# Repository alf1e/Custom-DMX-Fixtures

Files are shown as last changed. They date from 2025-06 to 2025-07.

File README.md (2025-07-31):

# Alfie's Custom DMX Fixtures
## What is this?
This project contains any relevant files for Custom DMX Fixtures project. In this repository you can find a PCB controller board, compatible with Neopixel LEDs using WLED. A fixture board which converts the signal sent from the controller to something usable by the Neopixel strip. And a LED Bar Fixture using the 24V version of the fixture control board.

## Why did you make this?
I volunteer at my school running our lighting rig for our shows. After one show in February, I realised something was missing and that it would look awesome with some kind of bar fixture. So I started this project and here we are now :D

# Images
Here are some relevant pictures of my project. Ill add more as I have then and as is needed.

## Control Board
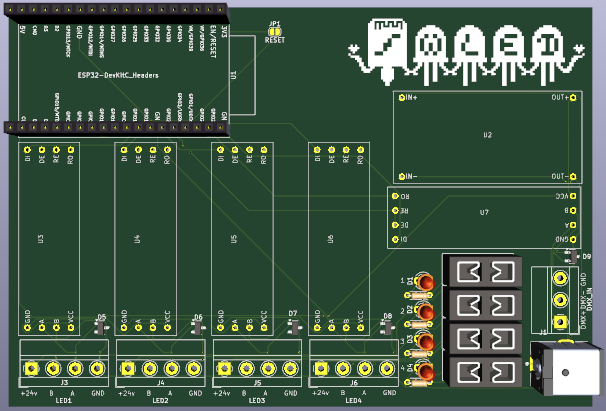
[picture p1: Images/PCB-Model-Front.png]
Picture of PCB Model Front

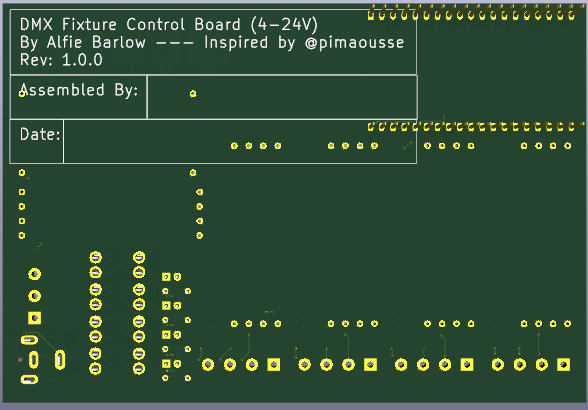
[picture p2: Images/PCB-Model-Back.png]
Picture of PCB Model Back


## 24V Fixture Board
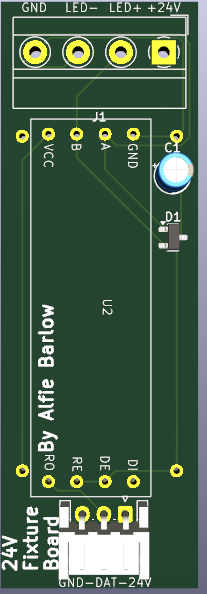
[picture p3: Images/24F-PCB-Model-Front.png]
Picture of PCB Model Front

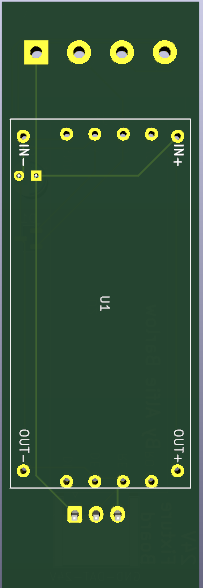
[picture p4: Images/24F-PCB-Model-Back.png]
Picture of PCB Model Back


# Firmware
For the firmware, you can use any compilation of WLED with DMX enabled.

You can compile WLED at [this website](https://wled-compile.github.io/?lang=en) using my config file in the root of this repository called `firmware.json`

# External Wiring
A DMX Fixture is basically a fancy name for a software controlled light, usually in a theatrical setting. My Fixtures are connected to the controlled using a GX12-4 cable matching 24V with 24V, A with LED-, B with LED+ and GND with GND. Relatively simple!

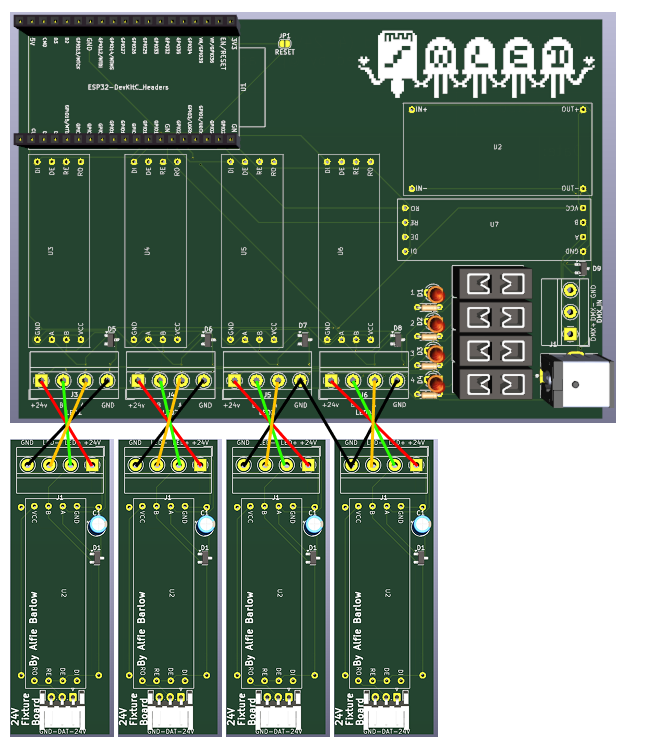
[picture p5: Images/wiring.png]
Picture of Wiring


# How to use.
Once you have the firmware installed there is 2 ways you can use this.

## No DMX
This can be purely controlled by any WLED control software. For mobile, I use WLED Native or just go to the IP of the controller on desktop. You can then change the colour and set effects through here

## DMX
This is a bit more complicated. Once you have connected the controller to your computer via a DMX interface you can open any DMX control software like QLC+ and import the configuration of the lights (Coming soon! I cant create a configuration without having at least a prototype) and then you can control the lights through QLC+. Remember to make sure you have no overlapping channels though!

# BOM
The following table and `BOM.csv` file are a combination of 4x 24V LED Bar Fixtures and 1x Control Board. For the individual BOMs see `BOM.md`

**Total BOM Cost: $223.09**

|Mrf# |Mfr. |Order Qty.|Unit Price(USD)|Ext.Price(USD)|LCSC# |Package |Min|Mult|SPQ |Availability|Stock Status|Customer Notes|Description |Product Link |
|---|---|---|---|---|---|---|---|----|----|---|---|---|---|---|
|TZ-L2-03YYBG2TDJ30-002|TUOZHAN |20 |0.0213 |0.43 |C779432  |Through Hole,D=3mm |20 |20  |1000|300 |In Stock | |Emerald Green 3mm Round Lens Through Hole,D=3mm LED Indication - Discrete ROHS |https://lcsc.com/product-detail/led-indication-discrete_tuozhan-tz-l2-03yybg2tdj30-002_C779432.html |
|NUP2105L |(DIOTEC) |10 |0.0899 |0.9 |C3700834 |SOT-23-3 |5  |5 |3000|45 |In Stock | |8A@8/20us 350W 44V 26.2V 24V SOT-23-3 ESD and Surge Protection (TVS/ESD) ROHS |https://lcsc.com/product-detail/esd-and-surge-protection-tvs-esd_diotec-nup2105l_C3700834.html |
|178.6165.0002 |Littelfuse |4 |2.1355 |8.54 |C207061  |Through Hole |1  |1 |500 |2007 |In Stock | |Through Hole Fuseholders ROHS |https://lcsc.com/product-detail/fuseholders_littelfuse-178-6165-0002_C207061.html |
|DB302-5.0-3P-GN-S |DORABO |5 |0.2851 |1.43 |C2997276 |P=5mm |5  |5 |500 |1085 |In Stock | |1x3P -40℃~+105℃ 30A 300V Green Through Hole 5mm 1 3 P=5mm Screw Terminal Blocks ROHS |https://lcsc.com/product-detail/screw-terminal-blocks_dorabo-db302-5-0-3p-gn-s_C2997276.html |
|2.54-1*4P |BOOMELE(Boom Precision Elec)|20 |0.0469 |0.94 |C2718488 |Through Hole,P=2.54mm |10 |10  |1000|38270 |In Stock | |2.54mm 1 3A 4P Bronze -40℃~+105℃ Through Hole 1x4P Top Square Hole Through Hole,P=2.54mm Female Headers ROHS |https://lcsc.com/product-detail/female-headers_boomele-boom-precision-elec-2-54-1-4p_C2718488.html |
|PM254-1-19-Z-8.5 |HCTL |5 |0.3055 |1.53 |C2897382 |Through Hole,P=2.54mm |5  |5 |120 |6380 |In Stock | |2.54mm 1 3A Copper Alloy 19P -40℃~+105℃ Through Hole 1x19P 8.5mm Top Square Hole Through Hole,P=2.54mm Female Headers ROHS  |https://lcsc.com/product-detail/female-headers_hctl-pm254-1-19-z-8-5_C2897382.html |
|ZX-PZ2.54-1-1PZZ |Megastar |20 |0.0116 |0.23 |C7501259 |Through Hole,P=2.54mm |20 |20  |2000|33300 |In Stock | |Gold 3A Through Hole Pin Header 2.5mm 1P 6mm -40℃~+105℃ 3mm 2.54mm Brass Black 1 1x1P Through Hole,P=2.54mm Pin Headers ROHS|https://lcsc.com/product-detail/pin-headers_megastar-zx-pz2-54-1-1pzz_C7501259.html |
|DB302-5.0-4P-GN-S |DORABO |8 |0.4435 |3.55 |C5143708 |Through Hole,P=5mm |1  |1 |200 |647 |In Stock | |20A 1x4P -40℃~+105℃ 300V Green Through Hole 5mm 1 4 Through Hole,P=5mm Screw Terminal Blocks ROHS |https://lcsc.com/product-detail/screw-terminal-blocks_dorabo-db302-5-0-4p-gn-s_C5143708.html |
|MFR-25FTE52-4K7 |YAGEO |50 |0.0117 |0.59 |C173023  |Through Hole,D2.4xL6.3mm |50 |50  |5000|62150 |In Stock | |Metal Film Resistor 4.7kΩ 250mW ±50ppm/℃ ±1% Through Hole,D2.4xL6.3mm Through Hole Resistors ROHS |https://lcsc.com/product-detail/through-hole-resistors_yageo-mfr-25fte52-4k7_C173023.html |
|0287002.PXCN |Littelfuse |5 |0.1083 |0.54 |C142680  |- |5  |5 |2000|2320 |In Stock | |32V 1kA Blade Fuse 2A Automotive Fuses ROHS |https://lcsc.com/product-detail/automotive-fuses_littelfuse-0287002-pxcn_C142680.html |
|DC-508-ARL250-H069 |XUNPU |1 |1.3904 |1.39 |C34388679|Through Hole |1  |1 |400 |357 |In Stock | |Right Angle DC Power Jack -40℃~+85℃ 2.5mm 5.7mm 20A 30V Through Hole DC Power Connectors ROHS |https://lcsc.com/product-detail/dc-power-connectors_xunpu-dc-508-arl250-h069_C34388679.html |
|S3B-EH(LF)(SN) |JST |10 |0.0458 |0.46 |C263754  |Through Hole,Right Angle,P=2.5mm|10 |10  |1000|60 |In Stock | |1x3P 3P EH Tin 3 -25℃~+85℃ 3A 1 2.5mm Brass Right Angle Through Hole,Right Angle,P=2.5mm Wire To Board Connector ROHS |https://lcsc.com/product-detail/wire-to-board-connector_jst-s3b-eh-lf-sn_C263754.html |
|- |- |5 |0.98 |4.9 |- |- |-  |- |- |- |- | |LM2596 |https://www.aliexpress.com/item/1005004904872120.html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 |
|- |- |9 |0.28 |2.52 |- |- |-  |- |- |- |- | |RS-485 TTL |https://www.aliexpress.com/item/1005005737922222.html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 |
|- |- |1 |3.42 |3.42 |- |- |-  |- |- |- |- | |ESP32-DevKitC |https://www.aliexpress.com/item/1005007820190456.html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 |
|- |- |1 |13.4 |13.4 |- |- |-  |- |- |- |- | |Control Board PCB | |
|- |- |4 |6 |24 |- |- |-  |- |- |- |- | |24V Fixture PCB | |
|- |- |4 |20.21 |80.84 |- |- |-  |- |- |- |- | |Polycarbonate Tube |https://www.ebay.co.uk/itm/276693351932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|
|- |- |4 |14.57 |58.28 |- |- |-  |- |- |- |- | |WS2811-COB |https://www.aliexpress.com/item/1005008502347105.html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 |
|- |- |1 |10.99 |10.99 |- |- |-  |- |- |- |- | |24V 10A PSU |https://www.aliexpress.com/item/1005005763465796.html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 |
|- |- |1 |3.04 |3.04 |- |- |-  |- |- |- |- | |DMX Input |https://www.aliexpress.com/item/1005007432049215.html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 |
|- |- |8 |0.32 |2.56 |- |- |-  |- |- |- |- | |Fixture Connectors |https://www.aliexpress.com/item/1005002920441877.html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 |

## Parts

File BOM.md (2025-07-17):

# DMX Control Board
* [BOM](https://github.com/alf1e/Custom-DMX-Fixtures/blob/main/DMX%20Control%20Board/BOM.csv)
* [Digikey BOM](https://github.com/alf1e/Custom-DMX-Fixtures/blob/main/DMX%20Control%20Board/BOM-digikey.csv)
* [Other BOM](https://github.com/alf1e/Custom-DMX-Fixtures/blob/main/DMX%20Control%20Board/BOM-other.csv)

# 24V Fixture Board
* [BOM](https://github.com/alf1e/Custom-DMX-Fixtures/blob/main/24V%Fixture%20Board/BOM.csv)
* [Digikey BOM](https://github.com/alf1e/Custom-DMX-Fixtures/blob/main/24V%Fixture%20Board/BOM-digikey.csv)
* [Other BOM](https://github.com/alf1e/Custom-DMX-Fixtures/blob/main/24V%Fixture%20Board/BOM-other.csv)

# 24V LED Bar Fixture
* [BOM](https://github.com/alf1e/Custom-DMX-Fixtures/blob/main/24V%LED%Bar%20Fixture/BOM.csv)

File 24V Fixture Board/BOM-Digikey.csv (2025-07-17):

Index | Manufacturer Part Number | Manufacturer Name | Description | Requested Quantity 1 | Pack Quantity 1 | Pack Type 1 | Digi-Key Part Number 1 | Unit Price 1 | Extended Price 1 | Product Notes
1 | PPTC041LFBN-RC | Sullins Connector Solutions | CONN HDR 4POS 0.1 TIN PCB | 2 | 2 | Box | S7002-ND | 0.37 | $0.74
2 | 87224-1 | TE Connectivity AMP Connectors | CONN HEADER VERT 1POS | 4 | 4 | Bulk | A26541-ND | 0.65 | $2.60
3 | NUP2105L | Diotec Semiconductor | TVS DIODE 24VWM 44VC SOT233 | 1 | 1 | Cut Tape (CT) | 4878-NUP2105LCT-ND | 0.23 | $0.23
4 | 31059104 | METZ CONNECT USA Inc. | SCREW TYPE, TERMINAL BLOCK, RIGH | 1 | 1 | Bulk | 1849-1341-ND | 2.12 | $2.12
5 | S3B-EH | JST Sales America Inc. | CONN HEADER R/A 3POS 2.5MM | 1 | 1 | Bulk | 455-S3B-EH-ND | 0.11 | $0.11

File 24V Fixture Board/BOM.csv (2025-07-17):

Index | Manufacturer Part Number | Manufacturer Name | Description | Requested Quantity 1 | Pack Quantity 1 | Pack Type 1 | Digi-Key Part Number 1 | Unit Price 1 | Extended Price 1 | Product Notes
1 | PPTC041LFBN-RC | Sullins Connector Solutions | CONN HDR 4POS 0.1 TIN PCB | 2 | 2 | Box | S7002-ND | 0.37 | $0.74
2 | 87224-1 | TE Connectivity AMP Connectors | CONN HEADER VERT 1POS | 4 | 4 | Bulk | A26541-ND | 0.65 | $2.60
3 | NUP2105L | Diotec Semiconductor | TVS DIODE 24VWM 44VC SOT233 | 1 | 1 | Cut Tape (CT) | 4878-NUP2105LCT-ND | 0.23 | $0.23
4 | 31059104 | METZ CONNECT USA Inc. | SCREW TYPE, TERMINAL BLOCK, RIGH | 1 | 1 | Bulk | 1849-1341-ND | 2.12 | $2.12
5 | S3B-EH | JST Sales America Inc. | CONN HEADER R/A 3POS 2.5MM | 1 | 1 | Bulk | 455-S3B-EH-ND | 0.11 | $0.11
6 | LM2596 | N/A |  | 1 | N/A | N/A | N/A | 0.98 | $0.98 | https://www.aliexpress.com/item/1005004904872120.html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
7 | RS-485 TTL | N/A |  | 1 | N/A | N/A | N/A | 0.28 | $0.28 | https://www.aliexpress.com/item/1005005737922222.html?mp=1
8 | PCB | N/A |  | 1 | N/A | N/A | N/A | 6 | $6

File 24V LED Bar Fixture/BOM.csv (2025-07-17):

Index | Manufacturer Part Number | Manufacturer Name | Description | Requested Quantity 1 | Pack Quantity 1 | Pack Type 1 | Digi-Key Part Number 1 | Unit Price 1 | Extended Price 1 | Product Notes
1 | N/A | N/A | 24V Fixture Board | 1 | N/A | N/A | N/A | 12.26 | $12.26
2 | N/A | N/A | N/A | 1 | N/A | N/A | N/A | 20.21 | $20.21 | https://www.ebay.co.uk/itm/276693351932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
3 | WS2811-FCOB | N/A | N/A | 1 | N/A | N/A | N/A | 14.57 | $14.57 | https://www.aliexpress.com/item/1005008502347105.html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

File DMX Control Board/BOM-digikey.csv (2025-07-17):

Index | Manufacturer Part Number | Manufacturer Name | Description | Requested Quantity 1 | Pack Quantity 1 | Digi-Key Part Number 1 | Unit Price 1 | Extended Price 1 | Product Notes
1 | 151031VS06000 | Würth Elektronik | LED GREEN DIFFUSED 3MM ROUND T/H | 4 | 4 | 732-5008-ND | 0.15 | $0.60
2 | NUP2105L | Diotec Semiconductor | TVS DIODE 24VWM 44VC SOT233 | 5 | 5 | 4878-NUP2105LCT-ND | 0.23 | $1.15
3 | 3568 | Keystone Electronics | FUSE HOLDER BLADE 500V 30A PCB | 4 | 4 | 36-3568-ND | 1.2 | $4.80
4 | 31271103 | METZ CONNECT USA Inc. | SCREW TYPE, TERMINAL BLOCK, RIGH | 1 | 1 | 1849-1335-ND | 1.56 | $1.56
5 | PPTC041LFBN-RC | Sullins Connector Solutions | CONN HDR 4POS 0.1 TIN PCB | 10 | 10 | S7002-ND | 0.313 | $3.13
6 | PPTC191LFBN-RC | Sullins Connector Solutions | CONN HDR 19POS 0.1 TIN PCB | 2 | 2 | S7017-ND | 1.05 | $2.10
7 | 87224-1 | TE Connectivity AMP Connectors | CONN HEADER VERT 1POS | 4 | 4 | A26541-ND | 0.65 | $2.60
8 | 31059104 | METZ CONNECT USA Inc. | SCREW TYPE, TERMINAL BLOCK, RIGH | 4 | 4 | 1849-1341-ND | 2.12 | $8.48
9 | CF12JT4K70 | Stackpole Electronics Inc | RES 4.7K OHM 5% 1/2W AXIAL | 4 | 4 | CF12JT4K70CT-ND | 0.1 | $0.40
10 | 0287002.PXCN | Littelfuse Inc. | FUSE AUTO 2A 32VDC BLADE ATO/ATC | 3 | 3 | F4192-ND | 0.39 | $1.17
11 | PJ-063AH | Same Sky (Formerly CUI Devices) | CONN PWR JACK 2X5.5MM SOLDER | 1 | 1 | CP-063AH-ND | 1.5 | $1.50
12 | 0287001.U | Littelfuse Inc. | FUSE AUTO 1A 32VDC BLADE ATO/ATC | 1 | 1 | 0287001.U-ND | 0.43 | $0.43

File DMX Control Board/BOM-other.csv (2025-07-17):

Index | Manufacturer Part Number | Manufacturer Name | Description | Requested Quantity 1 | Pack Quantity 1 | Digi-Key Part Number 1 | Unit Price 1 | Extended Price 1 | Product Notes
1 | LM2596 | N/A | N/A | 1 | N/A | N/A | 0.98 | $0.98 | https://www.aliexpress.com/item/1005004904872120.html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
2 | RS-485 TTL | N/A | N/A | 5 | N/A | N/A | 0.28 | $0.28 | https://www.aliexpress.com/item/1005005737922222.html?mp=1
3 | ESP32-DevKitC | N/A | N/A | 1 | N/A | N/A | 3.42 | $3.42 | https://www.aliexpress.com/item/1005007820190456.html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
4 | PCB | N/A | N/A | 1 | N/A | N/A | 13.4 | $13.4

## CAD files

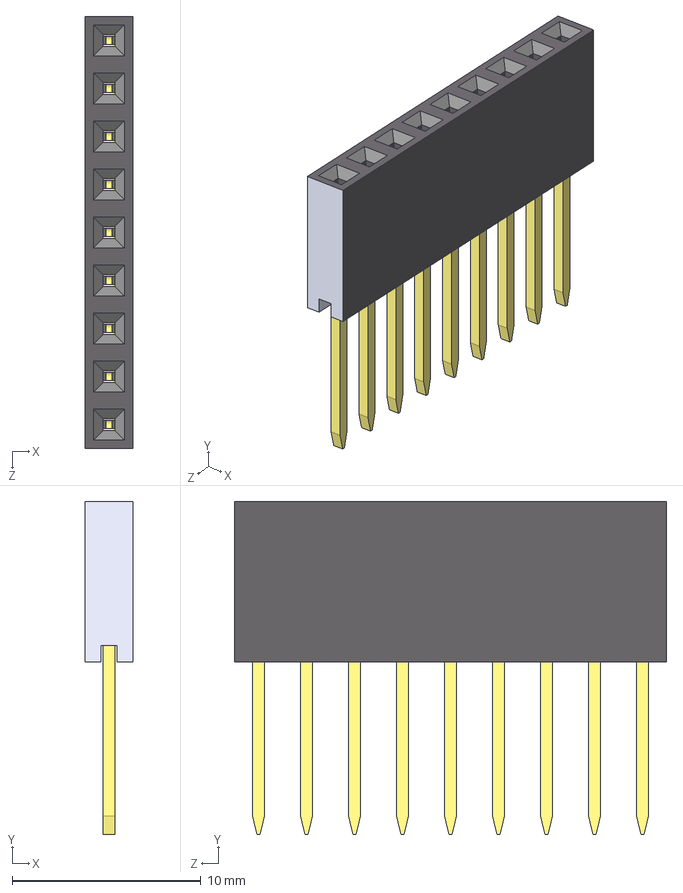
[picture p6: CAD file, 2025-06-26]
Models/header-female-15x1-1.snapshot.4/1x9.STEP
2.54 x 17.6 x 22.9 mm

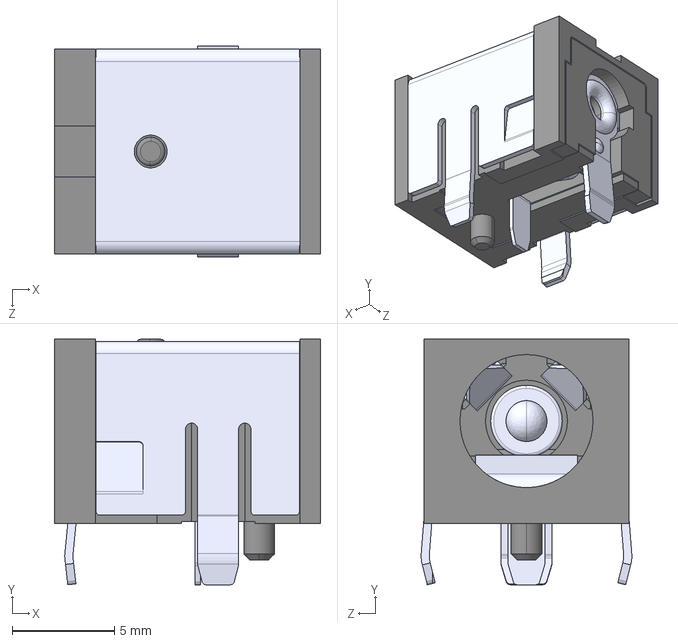
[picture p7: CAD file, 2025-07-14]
Models/PJ_063AH/PJ-063AH.step
13.0 x 12.0 x 10.3 mm

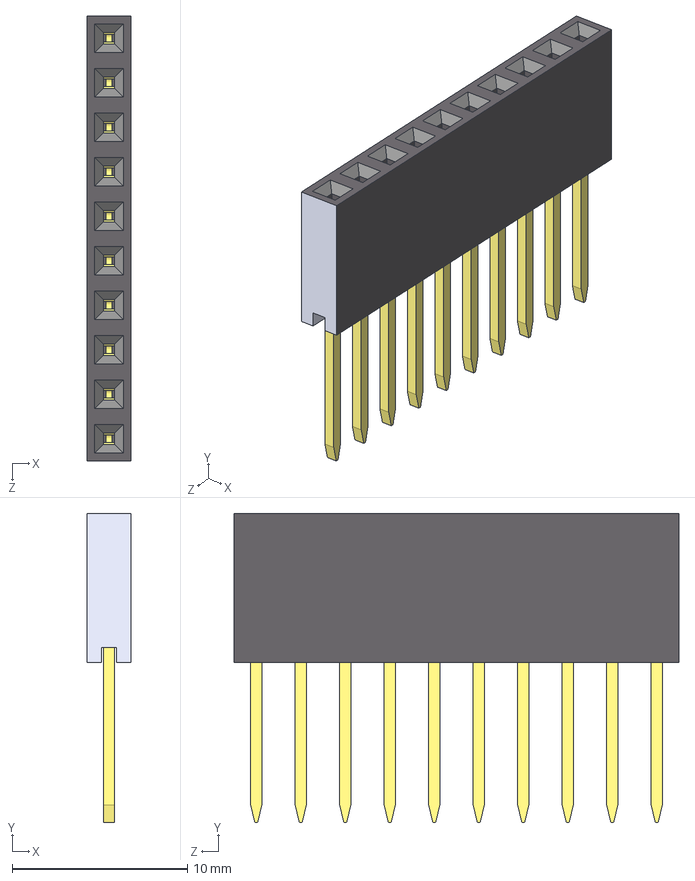
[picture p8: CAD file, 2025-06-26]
Models/header-female-15x1-1.snapshot.4/1x10.STEP
2.54 x 17.6 x 25.4 mm

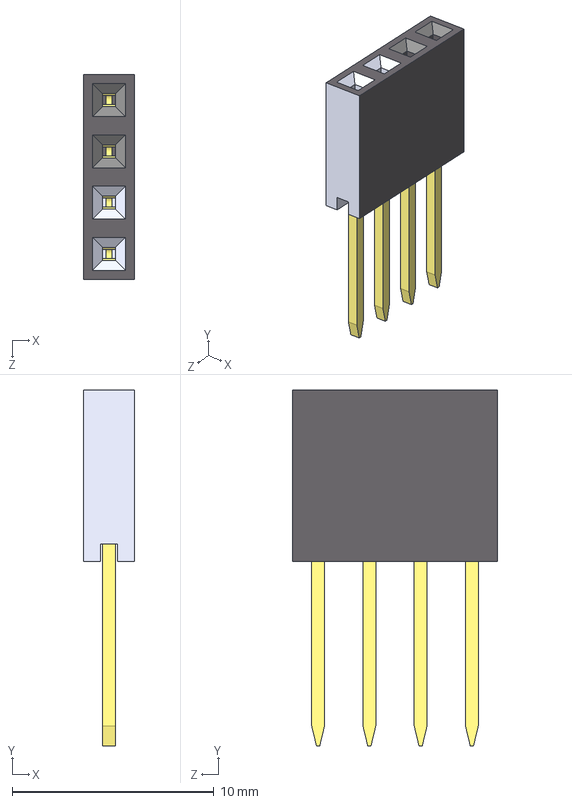
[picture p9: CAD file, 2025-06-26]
Models/header-female-15x1-1.snapshot.4/1x4.STEP
2.54 x 17.6 x 10.2 mm

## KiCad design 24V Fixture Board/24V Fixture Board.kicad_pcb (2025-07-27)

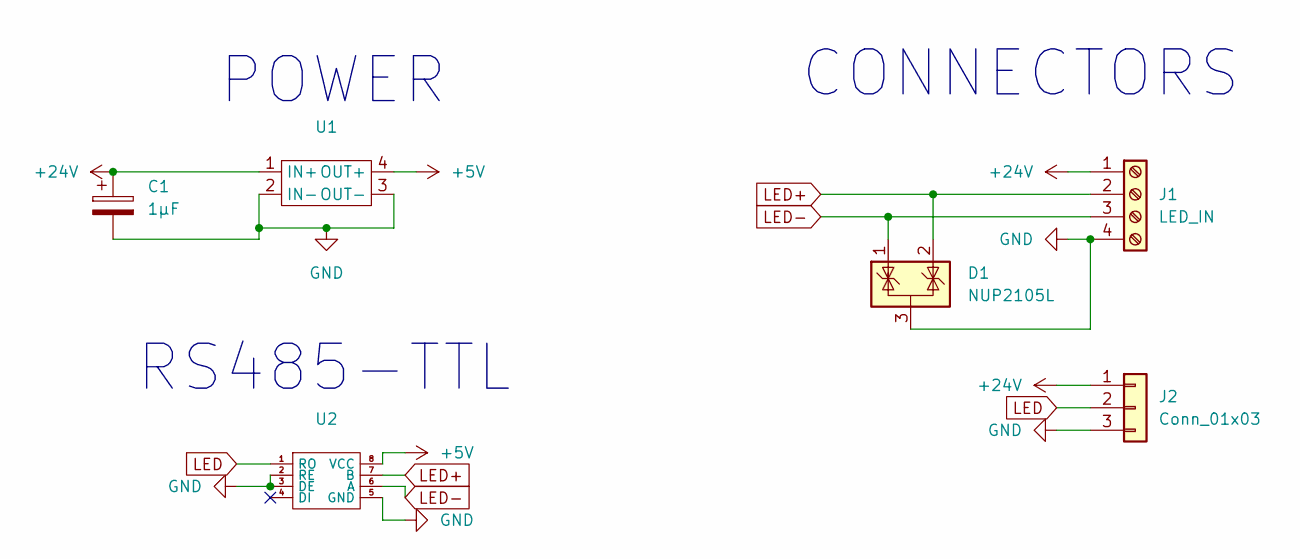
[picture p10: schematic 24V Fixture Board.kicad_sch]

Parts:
C1: 1μF; CP_Radial_D4.0mm_P2.00mm
D1: NUP2105L; SOT-23
J1: LED_IN; TerminalBlock_MetzConnect_Type011_RT05504HBWC_1x04_P5.00mm_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
J2: Conn_01x03; JST_EH_S3B-EH_1x03_P2.50mm_Horizontal
U1: LM2596S-Buck-Module
U2: Max485

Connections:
+5V: U1.4 (OUT+), U2.8 (VCC)
+24V: C1.1, J1.1, J2.1, U1.1 (IN+)
GND: C1.2, D1.3 (A), J1.4, J2.3, U1.2 (IN-), U1.3 (OUT-), U2.2 (RE), U2.3 (DE), U2.5 (GND)
LED: J2.2, U2.1 (RO)
LED+: D1.2 (K), J1.2, U2.7 (B)
LED-: D1.1 (K), J1.3, U2.6 (A)

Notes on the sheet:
CONNECTORS
POWER
RS485-TTL

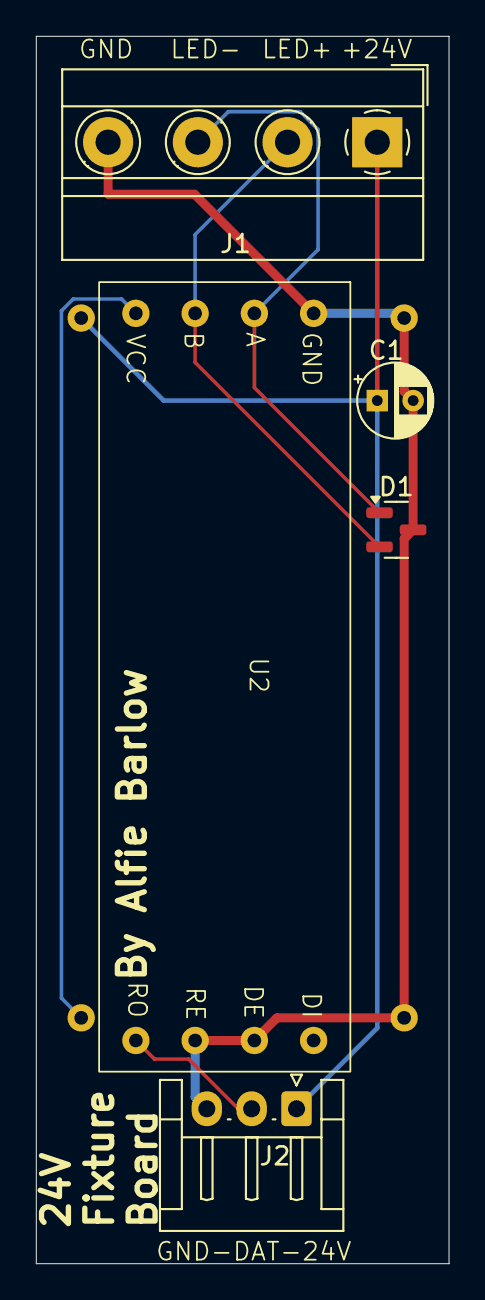
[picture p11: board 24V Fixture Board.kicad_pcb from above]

Board: 2 copper layers, 23.0 x 68.4 mm, 6 parts (1 on the bottom side), 6 nets.

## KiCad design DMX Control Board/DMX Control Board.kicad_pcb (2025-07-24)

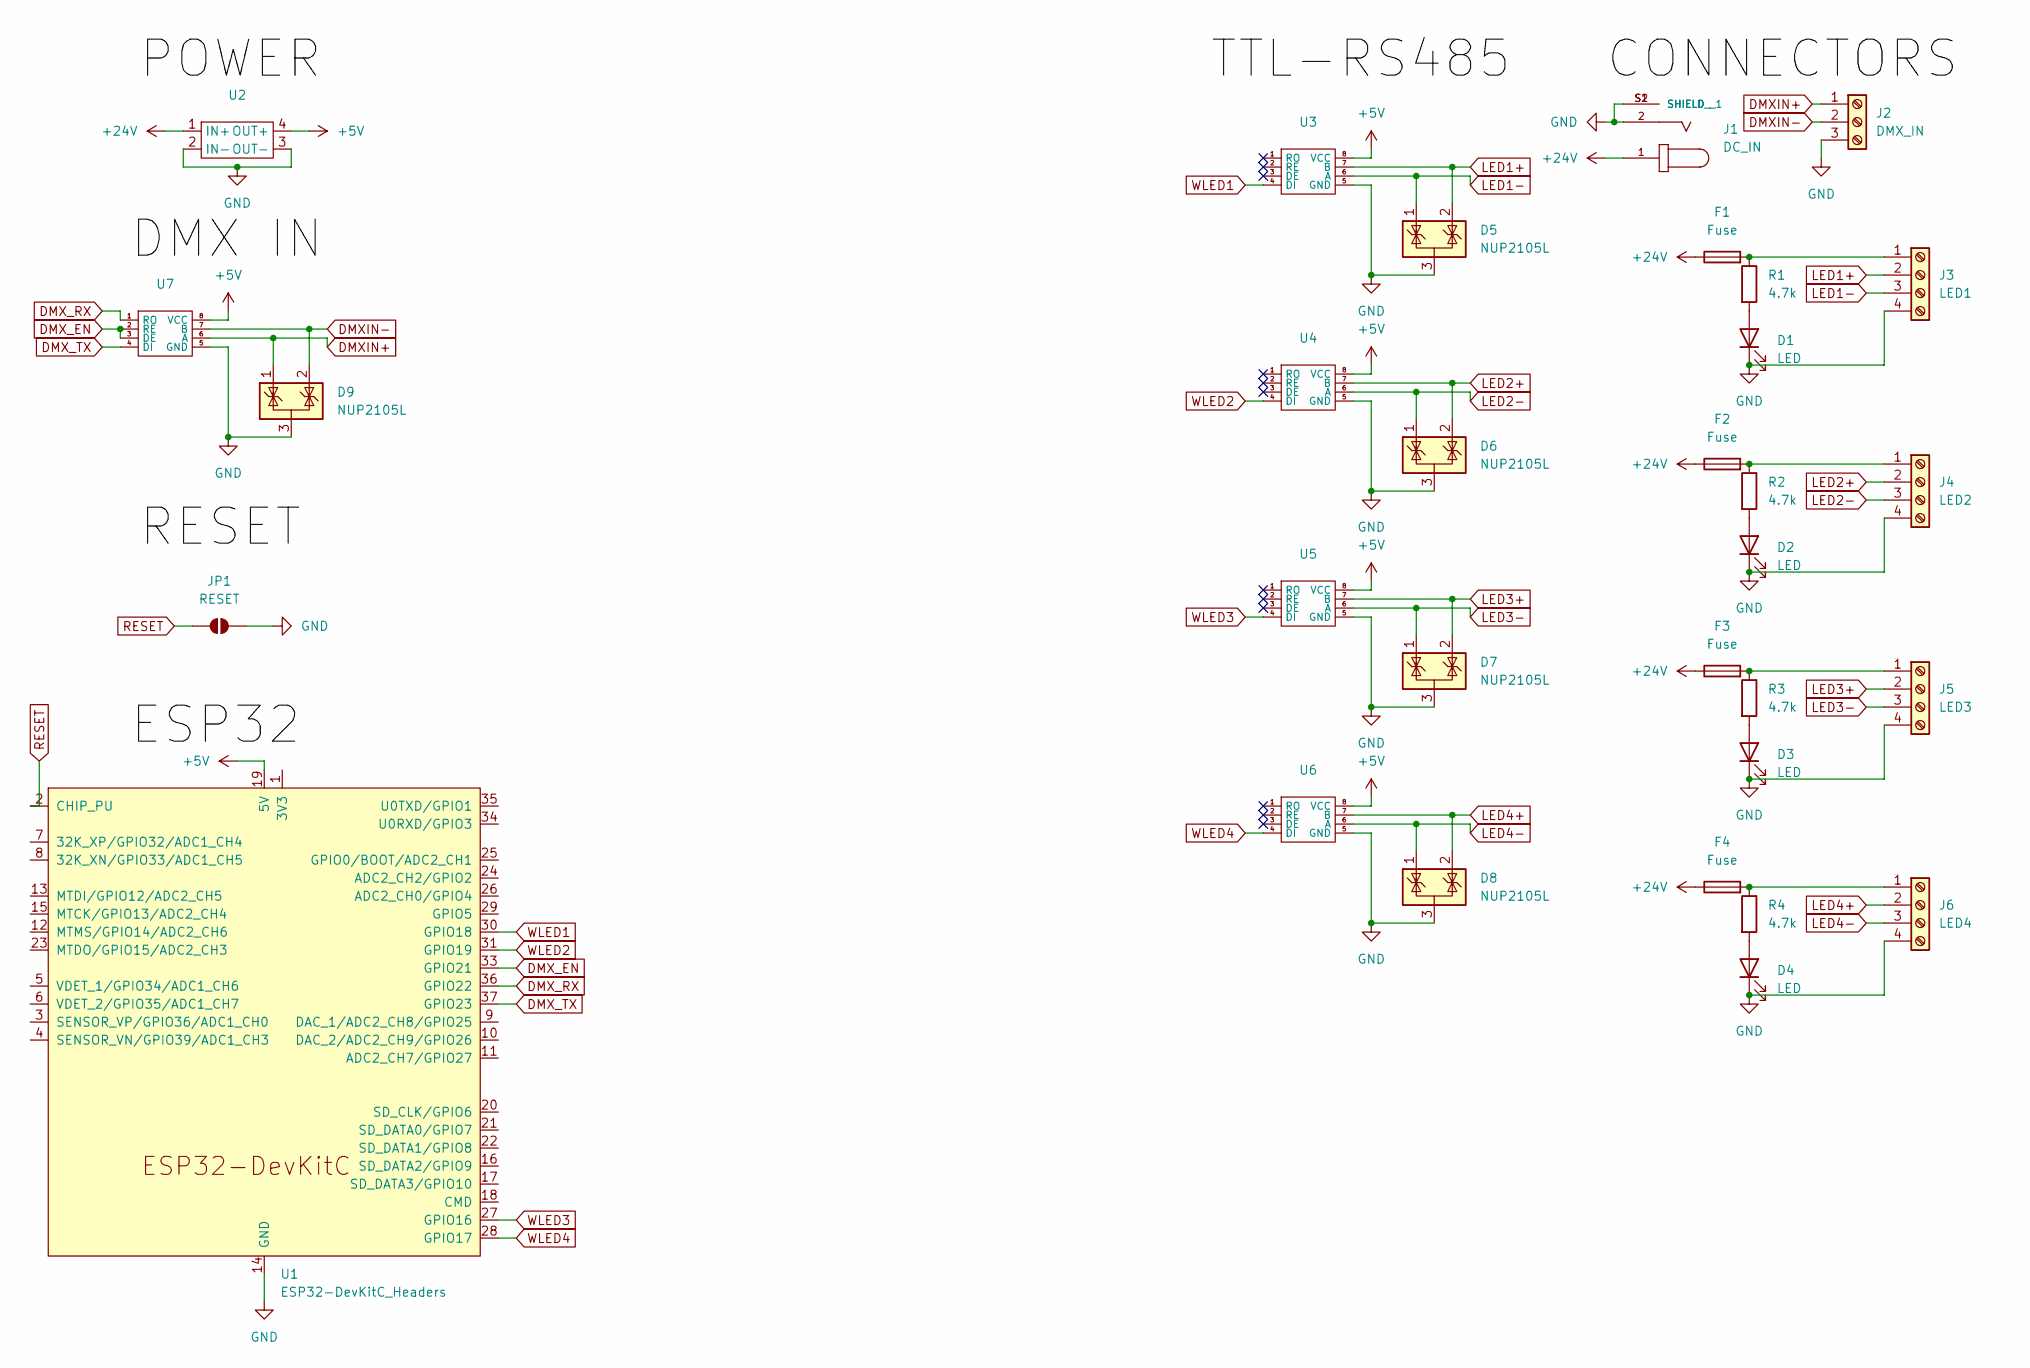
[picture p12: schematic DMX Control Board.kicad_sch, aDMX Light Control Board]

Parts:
D1, D2, D3, D4: LED; LED_D3.0mm
D5, D6, D7, D8, D9: NUP2105L; SOT-23
F1, F2, F3, F4: Fuse; FuseHolder_Blade_ATO_Littelfuse_FLR_178.6165
J1: DC_IN; CUI_PJ-063AH; PARTREV 1.02
J2: DMX_IN; TerminalBlock_MetzConnect_Type011_RT05503HBWC_1x03_P5.00mm_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
J3: LED1; TerminalBlock_MetzConnect_Type011_RT05504HBWC_1x04_P5.00mm_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
J4: LED2; TerminalBlock_MetzConnect_Type011_RT05504HBWC_1x04_P5.00mm_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
J5: LED3; TerminalBlock_MetzConnect_Type011_RT05504HBWC_1x04_P5.00mm_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
J6: LED4; TerminalBlock_MetzConnect_Type011_RT05504HBWC_1x04_P5.00mm_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
JP1: RESET; SolderJumper-2_P1.3mm_Open_RoundedPad1.0x1.5mm
R1, R2, R3, R4: 4.7k; R_Axial_DIN0204_L3.6mm_D1.6mm_P5.08mm_Horizontal
U1: ESP32-DevKitC_Headers
U2: LM2596S-Buck-Module
U3, U4, U5, U6, U7: Max485

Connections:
+5V: U1.19 (5V), U2.4 (OUT+), U3.8 (VCC), U4.8 (VCC), U5.8 (VCC), U6.8 (VCC), U7.8 (VCC)
+24V: F1.1, F2.1, F3.1, F4.1, J1.1, U2.1 (IN+)
DMXIN+: D9.1 (K), J2.1, U7.6 (A)
DMXIN-: D9.2 (K), J2.2, U7.7 (B)
DMX_EN: U1.33 (GPIO21), U7.2 (RE), U7.3 (DE)
DMX_RX: U1.36 (GPIO22), U7.1 (RO)
DMX_TX: U1.37 (GPIO23), U7.4 (DI)
GND: D1.1 (K), D2.1 (K), D3.1 (K), D4.1 (K), D5.3 (A), D6.3 (A), D7.3 (A), D8.3 (A), D9.3 (A), J1.2, J1.S1 (SHIELD), J1.S2 (SHIELD__1), J2.3, J3.4, J4.4, J5.4, J6.4, JP1.2 (B), U1.14 (GND), U1.32 (GND), U1.38 (GND), U2.2 (IN-), U2.3 (OUT-), U3.5 (GND), U4.5 (GND), U5.5 (GND), U6.5 (GND), U7.5 (GND)
LED1+: D5.2 (K), J3.2, U3.7 (B)
LED1-: D5.1 (K), J3.3, U3.6 (A)
LED2+: D6.2 (K), J4.2, U4.7 (B)
LED2-: D6.1 (K), J4.3, U4.6 (A)
LED3+: D7.2 (K), J5.2, U5.7 (B)
LED3-: D7.1 (K), J5.3, U5.6 (A)
LED4+: D8.2 (K), J6.2, U6.7 (B)
LED4-: D8.1 (K), J6.3, U6.6 (A)
unnamed: D1.2 (A), R1.2
unnamed: D2.2 (A), R2.2
unnamed: D3.2 (A), R3.2
unnamed: D4.2 (A), R4.2
unnamed: F1.2, J3.1, R1.1
unnamed: F2.2, J4.1, R2.1
unnamed: F3.2, J5.1, R3.1
unnamed: F4.2, J6.1, R4.1
RESET: JP1.1 (A), U1.2 (CHIP_PU)
WLED1: U1.30 (GPIO18), U3.4 (DI)
WLED2: U1.31 (GPIO19), U4.4 (DI)
WLED3: U1.27 (GPIO16), U5.4 (DI)
WLED4: U1.28 (GPIO17), U6.4 (DI)

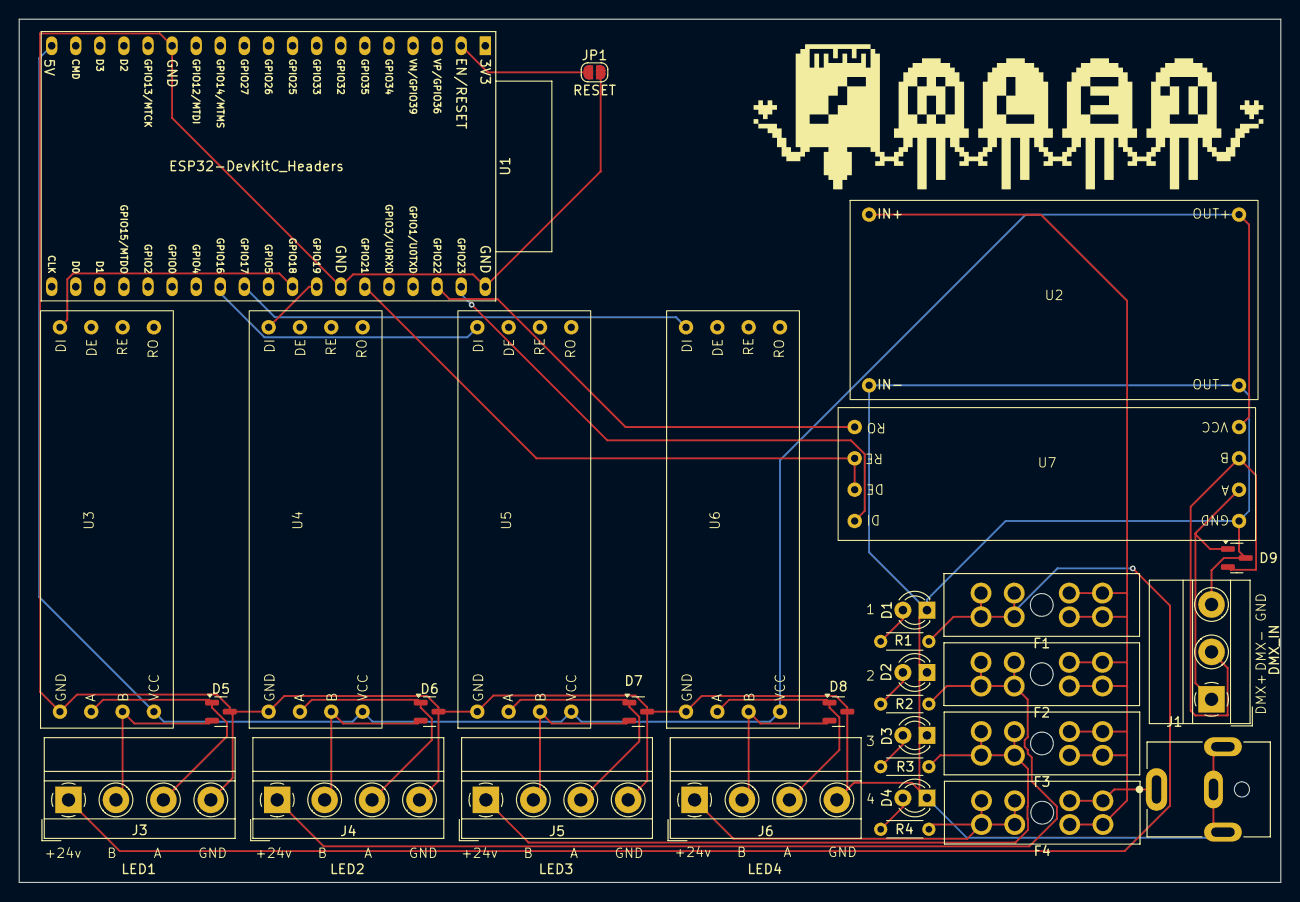
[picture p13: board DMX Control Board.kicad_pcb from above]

Board: 2 copper layers, 133.0 x 91.0 mm, 31 parts (0 on the bottom side), 29 nets.

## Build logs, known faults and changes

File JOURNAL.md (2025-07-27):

---
title: "Custom DMX Lighting Fixtures"
author: "Alfie Barlow"
description: "Custom DMX Light Fixtures powered by WLED and a custom controller."
created_at: "2025-06-24"
---

**Total Time: 26.75h**

# June 24th: Let it begin.
Today I began work on my project, designing the PCB for the control board. This board will send power and data to each fixture (up to 4 maximum) to allow me to control them. Im using some open source software call [WLED](https://kno.wled.ge/) for this.

I started the schematic off with the connectors. For inputs I have: power (+24v,10a) and DMX in (GND, DMXIN+, DMXIN-). For outputs I have: 3x Fixture Outputs (+24v with 2a fuse and status LED in series, LED1+, LED1- and GND), 1x Fixture Output (+24v with 1a fuse and status LED in series, LED1+, LED1- and GND).

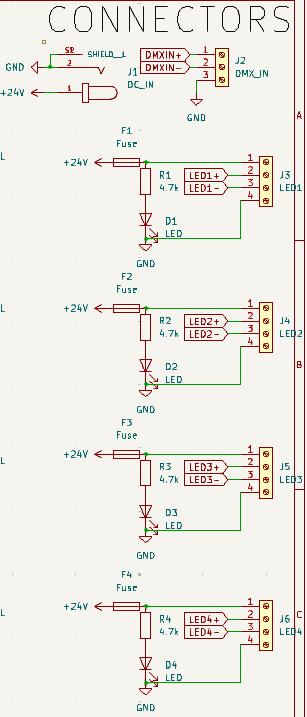
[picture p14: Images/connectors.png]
picture of connectors


Next, I added the RS-485 modules. Each module takes +5v, GND and data as an input and outputs LED(x)+ and LED(x)-. Both of these data lines are connected to a NUP1250L for ESD protection.

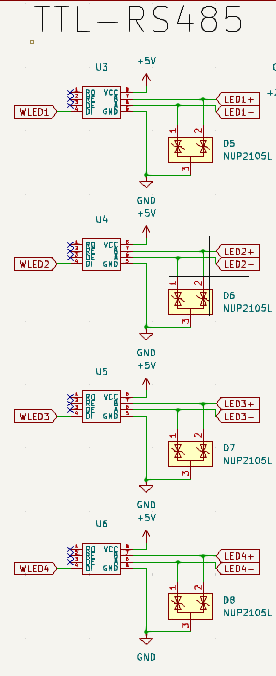
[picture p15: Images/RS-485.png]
picture of RS-485 modules


Next, I added some miscelaneous circuits. One of these will step down the 24v power to 5v using a buck converter and the other will decode the DMXIN- and DMXIN+ into DMX_RX, DMX-TX and DMX_EN. The data lines, DMXIN+ and DMXIN- have NUP2105L for ESD resistance.

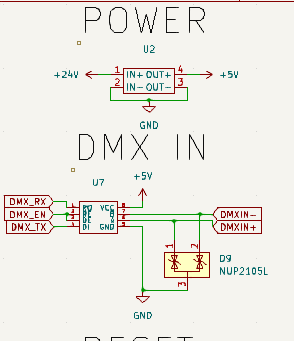
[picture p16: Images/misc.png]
picture of power and DMX IN


Finally, I added the ESP32. The ESP32 is connected to GND and +5V for power and the 4 LED data lines, WLED1, WLED2, WLED3 and WLED4. The ESP32 also takes the decoded dmx input with DMX_EN, DMX_RX and DMX_TX. The CHIP_PU pin on the ESP32 is also connected to a jumper to allow easy resetting of the ESP32 if it happens to lock up.

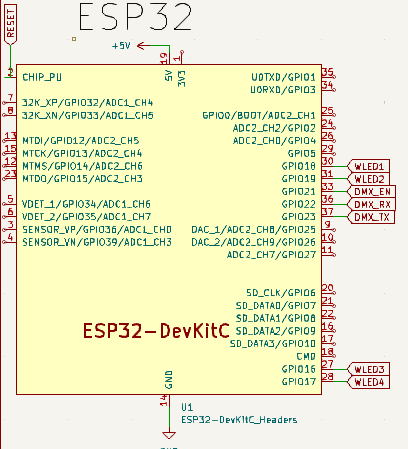
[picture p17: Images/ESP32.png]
picture of ESP32


**TIME TAKEN: 5h** Did I mention this is my *first time* desiging a PCB?

# June 25th: Actually getting into the PCB.
Happy 6 months to Christmas! Or if you dont celebrate, happy 6 months to December 25th!

Honestly Im not 100% sure what to write here as I kind of just worked through this and then remembered I need to do the journal.

Anyway, this was an absolute pain as I had to make footprints for my RS-485 and buck converters and I dont own calipers so who knows if they are correct! Once I got this done it went pretty painlessly and most of my troubles were just from learning KiCad.

Ive got a DC barrel jack for the power input and I'm using screw terminals for the DMX-IN and Fixture out. These will then connect to a 3-Pin XLR connect in the case of the DMX-IN and 4 GX12-4 connectors for the fixture outputs. However, I am not going to make a case for this until Im sure my PCB works. My 3D printer is currently broken and I dont have the time, nor money to fix it.

A couple more hours of running tracks, adding cool graphics and fixing errors raised by the DRC and I *think* it's done!

Also, a huge thanks to @pinamouse of the WLED discord server for being a huge inspiration for the controller :D

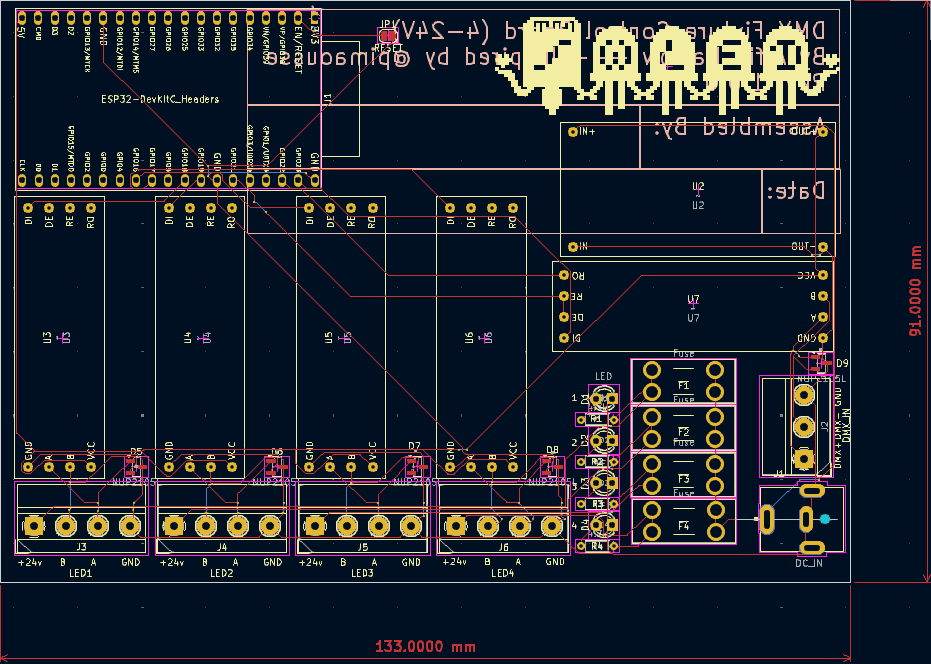
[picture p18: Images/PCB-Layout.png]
Picture of PCB Layout


Picture of PCB Model Front

Picture of PCB Model Back

**TIME TAKEN: 7h (estimate, sorry)**

# June 26th: Sorting out a BOM.
Today I spent an hour or two scrolling through Digikey to assemble a BOM for *most* of the resources required to assemble the PCB. The BOM does not include any of the buck converters, RS-485 modules or an ESP32 as these are not on Digikey. I will most likely obtain these through Aliexpress for a rough cost of no more than £10-20/unit. I will add these to the BOM at a later date. I have exported the BOM from digikey and you can find it in the `BOM.csv` file.

It was also at this point of the project where I had to redo at least a good half of the PCB Layout as I needed to change my fuse holder to one that wasnt unobtainium

My next steps now are adding mounting holes to the PCB and testing the circuit.

**Time Taken: 2h (also estimate, sorry)**

# June 27th: Getting the Fixture Board going!
In the future, I plan to make fixture boards supporting many different voltages, but for now I will focus on 24V fixtures with the `24V Fixture Board`.

__Schematic__
To start I need another 4-pin screw terminal that will be connected to a GX12-4 connector. Also, cant forget ESD protection on this side too! Also, a 3-pin JST connector is required for the fixture itself, outputting 24v, data and GND.

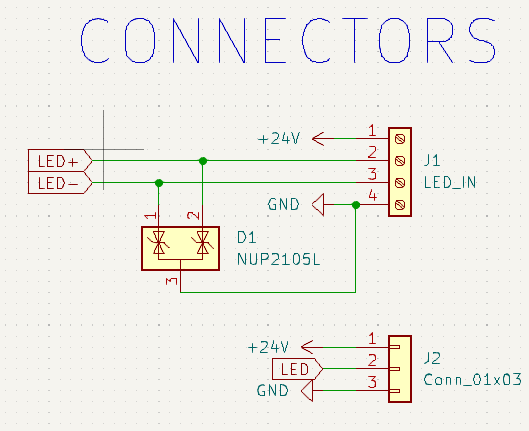
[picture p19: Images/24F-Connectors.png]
Picture of Connectors


Next, I need to handle power conversion. Same as last time really, just stick a buck converter in tuned to 5v and thats that done. However, a slight change is I need to add a capacitor to handle the voltage drop over the long cable to the fixture.

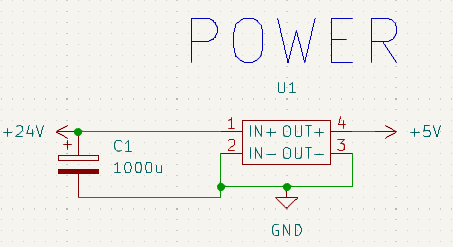
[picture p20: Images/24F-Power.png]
Picture of Power


Finally, just need the RS485 module to convert LED+ and LED- to a singular data line. Jusat a 5v input, LED+ to B, LED- to A, GND, connect LED to RO and connewct RE and DE to GND and thats all thats needed!

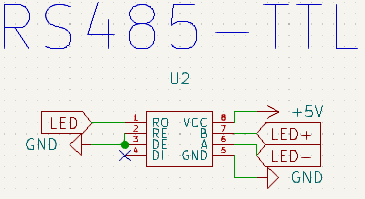
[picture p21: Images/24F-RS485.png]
Picture of RS485


__PCB__
Next step on the list, laying this all out on a board.

This started off with the usual hell of "Oh no I need to find footprints" and then guessing some, and probably soon changing them as any parts that would fit in that footprint are long obselete.

Once I got all the footprints together this was actually quite a simple layout. 4 pin header on one side, JST connector for the strip on the otherside and just throw all the parts in between and call it a day. However, this was my first time utilising both sides of the PCB so that proved to be interesting.

Add some graphics and text and boom, it done.

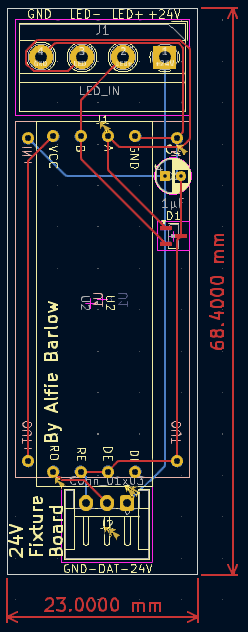
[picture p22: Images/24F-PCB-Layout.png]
Picture of finished PCB Layout


Picture of PCB Model Front

Picture of PCB Model Back

**Time Taken: 5h**

# June 28th: The BOM... (scary..!)
Once again, doing this fun stuff in 2 parts: the Digikey BOM and the "Other" BOM. Started off with the Digikey BOM and that was relitively easy as it used almost all of the same parts. The only item I needed to find was a 3-Pin horizontal JST connector which was easy enough.

Next up, the "Other" BOM for the 24V Fixture board. This is quite simple as all that is needed is a buck converter and a RS-485 module. this will include details for a case but as mentioned above, that is being left until I am sure everything works as my 3D printer is broken (parts are on route! but ebay shipping is pain). I alsoe needed to calculate a cost of the PCB which currently could change. This had been added to the BOM.

The "Other" BOM for the Control Board has also been created featuring basically the same parts + its own PCB which I do not expect the price of to change by much.

**Time Taken: 3h**

# June 14th: The BOM... (scary..!...again)
After a short break while I was away, I'm back at it again!

This time I have created the BOM for the fixture itself, consisting of a control board, the LED strip and the polycarbonate tube used to diffuse the LED. For the control board in this BOM I have just totalled the BOM of the `24V Fixture Board` and added this as an item to the BOM. 

**Time Taken: 45m**

# June 17th: More BOM work!
It was a sad, rainy day... Well it wasnt really I just hate BOMs. Anyway I started off by removing some useless columns from the Digikey BOM and reformating the other BOMs to use that format for easier combination. 

I then combined the digikey + other BOMs into 1 BOM.

Following this, I have combined the individual BOMs into one single BOM with 4x 24V LED Bar Fixtures and 1x Control Board.

Next, I made the README.md, added some pictures and put the BOM at the bottom like required.

Oh, I also went through and added links to the main BOM.

*my brain is a mess*

**Time Taken: 2.5h**

# June 24th: Fixing the submission.
I was informed by Highway that I need to use LCSC. So, I have spent some time finding the components I needed on LCSC and changing components where nessecary.

While I was doing this, I have basically redone all the trace layout because I kind of had to anyway.

I attempted to contact WeProFab for a quote for the Polycarbonate tube but was met with no response so I will have to stick with my eBay supplier for now.

**Time Taken: 1.5h**

# --- APPROVED FOR HIGHWAY | BELOW THIS LINE IS NOT INCLUDED IN TOTAL TIME ---

# June 27th: Safety is key.
Safety is key, and this is why i decided default track width was NOT a good decision for 8 amps, so I changed this.

I have also changed to a 10A capable barrel jack and replaced the randon 1A fuse with a 2A one.

**Time Taken: 1h**

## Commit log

2025-06-26 Oopsie forgot some files
    [BOM-digikey.csv]
2025-06-26 Fix the BOM
    [BOM-digikey.csv]
2025-06-27 27/06 Dump
    [24V Fixture Board.kicad_pcb, 24V Fixture Board.kicad_sch]
2025-06-28 Add BOM
    [24V Fixture Board.kicad_sch, BOM-Digikey.csv]
2025-06-28 Add todays work
    [BOM-Other.csv]
2025-06-28 I did a boo boo with the bom bom
    [BOM-other.csv]
2025-07-14 Do some more BOMs and add models
    [BOM.csv, PJ-063AH.step]
2025-07-17 Big super-duper mega commit
    [BOM-Digikey.csv, BOM-digikey.csv, BOM-other.csv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]
2025-07-17 Fix BOM in README.md
2025-07-24 The Great Fixit
    [BOM.csv, DMX Control Board.kicad_pcb, DMX Control Board.kicad_sch]
2025-07-27 27th Mega Commit
    [24V Fixture Board.kicad_pcb, BOM.csv, DMX Control Board.kicad_sch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]
2025-07-27 Remove the test file
    [DMX Control Board_ttest.kicad_pcb]
2025-07-31 Add wiring guide
2025-07-31 Add wiring guide image
